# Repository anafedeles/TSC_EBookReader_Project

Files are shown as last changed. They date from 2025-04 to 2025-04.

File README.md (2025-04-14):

# TSC_EBookReader_Project

## 
Proiectul **EOpenBook** este o platformă portabilă cu afișaj E-Paper, construită în jurul microcontrollerului ESP32-C6, cu scopul de a oferi o interfață de citire eficientă energetic și complet conectată. Include funcționalități precum:

- Afișare E-Paper cu consum redus
- Stocare locală pe memorie NOR și card microSD
- Monitorizare baterie și încărcare
- Ceas în timp real (RTC)
- Senzor de mediu cu detecție VOC
- Protecții ESD și rutare optimizată

## Diagramă bloc cu toate componentele proiectului
Copie a fișierului Diagrama Bloc

## Listă de materiale (BOM)

| Componentă | Link pentru achizitionare | Link Datasheet |
|---|---|---|
| 112A-TAAR-R03 ATTEND | https://store.comet.srl.ro/Catalogue/Product/43497/ | https://www.snapeda.com/parts/112A-TAAR-R03/Attend/datasheet/ |
| BD5229G-TR | https://www.digikey.com/en/products/detail/rohm-semiconductor/BD5229G-TR/3663792 | https://fscdn.rohm.com/en/products/databook/datasheet/ic/power/voltage_detector/bd52xxg-e.pdf |
| ESP32 WROVER BME680 Sensor | https://store.comet.srl.ro/Catalogue/Product/50164/ | https://www.bosch-sensortec.com/media/boschsensortec/downloads/datasheets/bst-bme680-ds001.pdf |
| LED CHG_LED | https://ro.mouser.com/ProductDetail/Kingbright/KP-1608SURCK?qs=2JU0tDl2GZ3FuyEWfBV1%2Fg== | https://www.snapeda.com/parts/KP-1608SURCK/Kingbright/datasheet/ |
| Condensator C0402 | https://ro.mouser.com/c/passive-components/capacitors/ceramic-capacitors/?q=CC0402 | https://componentsearchengine.com/Datasheets/2/CC0402MRX5R5BB106.pdf |
| Condensator Tant  | https://ro.mouser.com/ProductDetail/KYOCERA-AVX/TAJW107M010RNJ?qs=Wtp%252Bf%2FAeVqIH8v1VxV%252B1Rg%3D%3D | https://ro.mouser.com/datasheet/2/40/TAJ-3165264.pdf |
|Q1 DMG2305UX-7 | https://www.digikey.com/en/products/detail/diodes-incorporated/DMG2305UX-7/4340666 | https://www.diodes.com/assets/Datasheets/DMG2305UX.pdf |
| RTC MODULE DS3231SN# | https://www.snapeda.com/parts/DS3231SN%23/Analog+Devices/view-part/?ref=eda | https://www.snapeda.com/parts/DS3231SN%23/Analog%20Devices/datasheet/ |
| ESP32 C6 WROOM-1-N8 | https://ro.mouser.com/ProductDetail/Espressif-Systems/ESP32-C6-WROOM-1-N8?qs=8Wlm6%252BaMh8ST02Gmwp74cw%3D%3D | https://www.snapeda.com/parts/ESP32-C6-WROOM-1-N8/Espressif%20Systems/datasheet/ |
| FH34SRJ-24S-0.5SH(99)  | https://ro.mouser.com/ProductDetail/Hirose-Connector/FH34SRJ-24S-0.5SH99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 | https://www.snapeda.com/parts/FH34SRJ-24S-0.5SH(99)/Hirose%20Connector/datasheet/ |
| MAX 17048G+T10 | https://www.snapeda.com/parts/MAX17048G+T10/Analog+Devices/view-part/?ref=eda  | https://www.snapeda.com/parts/MAX17048G+T10/Analog%20Devices/datasheet/ |
| MBR0530 Schottky Diode | https://www.snapeda.com/parts/MBR0530/Onsemi/view-part/?ref=snap | https://www.snapeda.com/parts/MBR0530/ON%20Semiconductor/datasheet/ |
| ESP32 WROVER MCP73831 Power Management | ]https://www.snapeda.com/parts/BME680/Bosch/view-part/?welcome=home | https://www.snapeda.com/parts/MCP73831T-2ACI/OT/Microchip/datasheet/ |
| PFMF.050.1 | https://ro.mouser.com/ProductDetail/EPCOS-TDK/B72520T0350K062?qs=dEfas%2FXlABIszF52uu7vrg%3D%3D | https://www.tdk-electronics.tdk.com/inf/75/db/CTVS_14/Surge_protection_series.pdf |
| PGB1010603MR | https://www.snapeda.com/parts/PGB1010603MR/Littelfuse/view-part/?ref=eda | https://www.snapeda.com/parts/PGB1010603MR/Littelfuse%20Inc./datasheet/ |
| QWIIC_RIGHT_ANGLE CONNECTOR | https://ro.mouser.com/ProductDetail/SparkFun/PRT-14417?qs=wd5RIQLrsJhgdz%2FpmZ%2F3GQ== | https://ro.mouser.com/datasheet/2/813/Qwiic_Connector_Datasheet-1223982.pdf |
| Rezistență R0402 | https://grabcad.com/library/resistor-0402-1)  | https://www.yageo.com/upload/media/product/products/datasheet/rchip/PYu-RC_Group_51_RoHS_L_12.pdf |
| SD0805S020S1R0 | https://ro.mouser.com/ProductDetail/KYOCERA-AVX/SD0805S020S1R0?qs=jCA%252BPfw4LHbpkAoSnwrdjw%3D%3D | https://ro.mouser.com/datasheet/2/40/schottky-3165252.pdf |
| Si1308EDL-T1-GE3 MOSFET | https://www.snapeda.com/parts/SI1308EDL-T1-GE3/Vishay+Siliconix/view-part/?welcome=home&ref=eda | https://www.snapeda.com/parts/SI1308EDL-T1-GE3/Vishay%20Siliconix/datasheet/ |
| USB4110-GF-A | https://ro.mouser.com/ProductDetail/GCT/USB4110-GF-A?qs=KUoIvG%2F9IlYiZvIXQjyJeA%3D%3D | https://ro.mouser.com/datasheet/2/837/GCT_USB4110_Product_Drawing___20k_cycles-3455479.pdf |
| USBLC6-2SC6Y | https://ro.mouser.com/ProductDetail/STMicroelectronics/USBLC6-2SC6Y?qs=gNDSiZmRJS%2FOgDexvXkdow%3D%3D | https://ro.mouser.com/datasheet/2/389/usblc6_2sc6y-1852505.pdf |
| W25Q512JVEIQ | ]https://www.snapeda.com/parts/W25Q512JVEIQ/Winbond+Electronics/view-part/?ref=eda) | https://www.winbond.com/resource-files/W25Q512JV%20SPI%20RevB%2006252019%20KMS.pdf) |
| XC6220A331MR-G | https://componentsearchengine.com/part-view/XC6220A331MR-G/Torex | https://product.torexsemi.com/system/files/series/xc6220.pdf |
| 744043680 BOBINA  | https://ro.mouser.com/ProductDetail/Wurth-Elektronik/744043680?qs=PGXP4M47uW6VkZq%252BkzjrHA%3D%3D | https://www.we-online.com/components/products/datasheet/744043680.pdf |

## Funcționalitatea Hardware 
ESP32-C6 este nucleul EOpenBook-ului, oferind conectivitate Wi-Fi 6 și Bluetooth 5.0 LE. Acesta include:

### Procesor RISC-V single-core de 160MHz
512KB de SRAM
8MB de memorie flash externă
Conectivitate wireless integrată
Multiple pini GPIO pentru interfațarea cu componente periferice

### Afișaj E-Paper

Afișajul e-paper oferă o interfață vizuală cu consum redus pentru EBook
Conectat prin interfața SPI la ESP32-C6
Utilizează driver-ul BD5229G-TR pentru a gestiona diversele tensiuni necesare afișajului
Alimentarea afișajului este controlată de MOSFET-uri pentru a asigura oprirea completă când nu este utilizat
Conectorul afișajului (FH34SRJ-24S-0.5SH) oferă o conexiune fiabilă la modulul flexibil de afișare

### Senzor de Mediu

Senzorul BME688 oferă măsurători pentru:

Temperatură (precizie ±0.5°C)
Umiditate (precizie ±3% RH)
Presiune (precizie ±0.12 hPa)
Calitatea aerului (detectare VOC)
Conectat prin interfața I²C (SCL/SDA)
Funcționează la 3.3V cu un consum tipic de curent de 3.7mA în timpul măsurătorilor

### Gestionarea Energiei

Conector USB-C (112A-TAAR-R03) pentru alimentare și comunicare de date
USBLC6-2SC6Y oferă protecție ESD pentru liniile USB
MCP73831 controller pentru încărcarea bateriei Li-Ion/Li-Polymer cu o singură celulă:

Curent de încărcare programabil până la 500mA
Terminare automată a încărcării
Indicare status prin LED

MAX17048G+T10 monitorizează starea bateriei:

Oferă o estimare precisă a stării de încărcare (SoC)
Comunică prin I²C
Consum redus de energie (23μA)

XC6220A331MR-G LDO oferă o ieșire stabilă de 3.3V:

Interval de tensiune de intrare: 2.0V până la 6.0V
Curent de ieșire până la 700mA
Tensiune de dropout scăzută (90mV tipic la 100mA)

### Ceas în Timp Real

DS3231SN RTC de înaltă precizie:

Oscilator cu cristal compensat în temperatură (TCXO)
Precizie ±2ppm (±1 minut pe an)
Baterie de backup folosind un supercondensator
Interfață I²C pentru comunicare
Funcții de alarmă cu capacitate de întrerupere

### Stocare Externă

W25Q512JVEIQ 512Mb (64MB) Flash NOR Serial:

Interfață SPI la până la 133MHz
100.000 de cicluri de programare/ștergere
Retenție date: 20 de ani
Folosit pentru stocarea datelor aplicației, configurare și actualizări firmware

Interfață card SD pentru stocare extensibilă:

Conectată prin interfață SPI
Suportă formate standard de card SD

### Protecție ESD

Diodele PGB1010603MR protejează liniile SPI sensibile
USBLC6-2SC6Y protejează liniile de date USB
Layout-ul atent al PCB-ului cu planuri de masă și rutare corespunzătoare îmbunătățește performanța EMI/EMC

### Analiza Consumului de Energie

Mod de repaus: <50μA (ESP32-C6 în deep sleep, RTC activ)
Mod inactiv: ~25mA (ESP32-C6 treaz, periferice în standby)
Mod activ: ~150mA (toate sistemele active, fără a include reîmprospătarea afișajului)
Reîmprospătare afișaj: ~20mA vârf în timpul reîmprospătării, 0mA când este static
Estimare durată de viață a bateriei:

Cu o baterie tipică LiPo de 2000mAh
~80 de ore de funcționare continuă în mod inactiv
~2-3 săptămâni cu modele tipice de utilizare (treziri periodice și actualizări ale afișajului)

## Alocarea Pinilor ESP32-C6

| Componentă | Pini ESP32-C6 (funcție) | Note / Utilizare |
|---|---|---|
| **E-Paper Display** | IO3 (EPD_BUSY), IO5 (EPD_DC), IO6 (SCK), IO7 (MOSI), IO10 (EPD_CS), IO23 (EPD_RST), IO20 (EPD_3V3_C) | Interfață SPI; include semnalizare BUSY și control reset/alimentare |
| **Magistrala I2C** | IO21 (SDA), IO22 (SCL), IO19 (I2C_PW) | Comun pentru BME688, MAX17048, DS3231; I2C_PW pentru control alimentare senzori  |
| **RTC DS3231SN** | IO0 (INT_RTC), IO1 (32KHz), IO18 (RTC_RST) | Întrerupere externă, semnal 32KHz opțional, reset hardware |
| **USB** | IO12 (USB_D-), IO13 (USB_D+) | Comunicație USB cu PC |
| **UART** | IO16 (TX), IO17 (RX) | Comunicație serială pentru programare/debug |
| **Card SD** | IO2 (MISO), IO4 (SS_SD), IO6 (SCK), IO7 (MOSI) | SPI partajat; CS dedicat pentru card SD |
| **Memorie Flash NOR** | IO11 (FLASH_CS), IO2 (MISO), IO6 (SCK), IO7 (MOSI) | Partajează SPI cu SD și EPD; CS dedicat |
| **Butoane** | EN (RESET), IO8 (IO/BOOT), IO15 (IO/CHANGE) | BOOT pentru mod programare; CHANGE pentru acțiuni personalizate |
| **Alimentare & GND** | Pin 2 (3V3), Pin 1 (GND) | Alimentare stabilă 3.3V; masă comună |

Bus SPI: Bus-ul SPI este partajat între mai multe dispozitive (afișaj, flash, card SD) pentru a minimiza utilizarea pinilor. Fiecare dispozitiv are un pin dedicat de selectare a chip-ului pentru a asigura o comunicare corectă.
Bus I2C: Un singur bus I2C conectează toate dispozitivele I2C (BME688, RTC, indicator baterie) pentru a minimiza utilizarea pinilor, oferind în același timp o comunicare fiabilă la viteze standard (100kHz-400kHz).
Pini GPIO: Pinii cu capacitate de întrerupere (IO13, IO19) au fost selectați pentru funcții care necesită funcționalitate de trezire.
UART: Pinii standard UART (IO16/IO17) sunt utilizați pentru programare și depanare pentru a asigura compatibilitatea cu instrumentele standard de dezvoltare.
Gestionarea Energiei: Pinii de control pentru domeniile de alimentare sunt configurați pentru a permite controlul individual al perifericelor pentru o gestionare optimă a energiei.

## Detalii Suplimentare de Proiectare

Pentru a preveni eventualele erori la nivelul plăcii PCB, am ajustat dimensiunile anumitor footprint-uri și am corectat pad-urile, astfel încât să respecte normele de funcționare corespunzătoare. De asemenea, am aplicat regulile din checklist-ul de proiectare, inclusiv poziționarea condensatorilor de decuplare cât mai aproape de pinii VCC ai circuitelor integrate.
### Asezarea TP-urilor: 
TP-urile au fost amplasate strategic în apropierea marginilor plăcii de circuit imprimat și în vecinătatea componentelor cheie. Această alegere facilitează accesul pentru operațiunile de depanare și testare.
### Diode (Montare pe Suprafață ):
Designul inițial al amprentei pentru diode prezenta orificii de contact (pad holes) cu un diametru insuficient, ceea ce ar fi putut genera dificultăți semnificative în procesul de lipire. Pentru a asigura o fabricație fără probleme și o conexiune electrică solidă, dimensiunea acestor orificii a fost revizuită.
### Rutare și Plan de Masă: 
Rutarea traseelor a fost realizată atât pe stratul superior, cât și pe stratul inferior al PCB-ului. Această strategie a necesitat utilizarea unui total de 105 vias pentru a interconecta diferitele straturi și a permite o rutare complexă a semnalelor. Deși un număr mare de vias poate influența costul și complexitatea fabricației, utilizarea ambelor straturi oferă o flexibilitate sporită în distribuția semnalelor și a alimentării. Planul de masă (GND) a fost implementat după finalizarea rutării, fiind aplicat pe ambele straturi ale plăcii (superior și inferior). 
În realizarea designului am urmărit respectarea riguroasă a regulilor impuse de ERC și DRC. Amplasarea componentelor a fost realizată pe baza documentației tehnice disponibile (dimensiuni și recomandări de plasare), dar și ținând cont de cerințele de rutare și de asigurarea unei funcționări optime a dispozitivului.

## Concluzie

Designul hardware al proiectului **EOpenBook** îmbină performanța, eficiența energetică și modularitatea. Fiecare componentă a fost atent aleasă și integrată cu respectarea standardelor de proiectare (ERC/DRC). PCB-ul rezultat este pregătit pentru fabricație și testare, având o structură robustă, consum redus și compatibilitate excelentă cu cerințele mecanice.

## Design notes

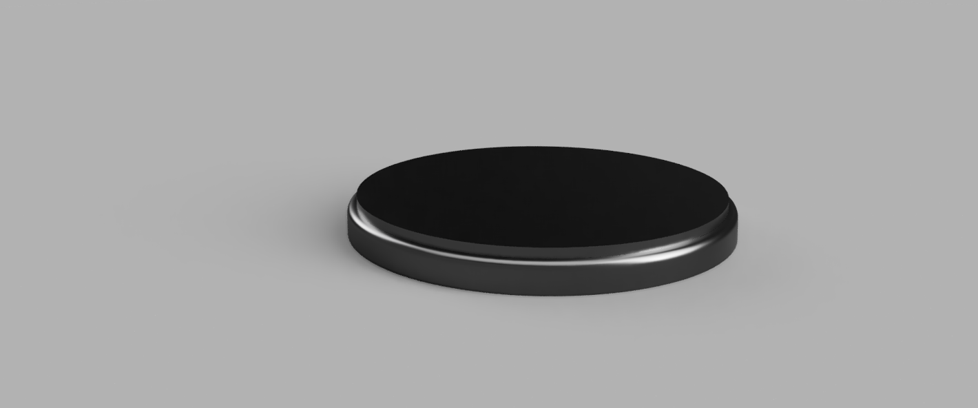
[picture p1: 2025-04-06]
Images/TP.jpg

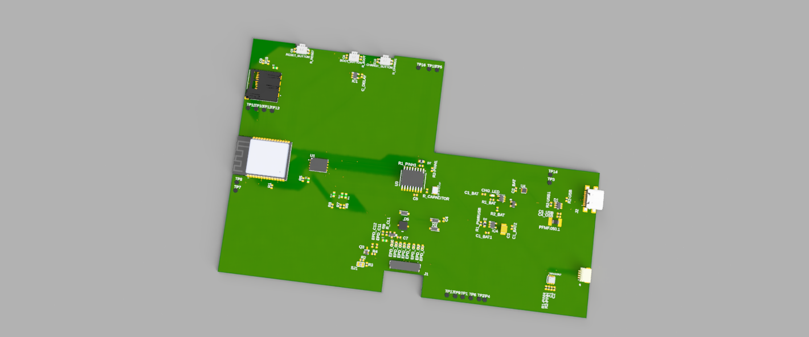
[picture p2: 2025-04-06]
Images/089be8cc-ee63-4535-a1ee-0e397a65c211.PNG

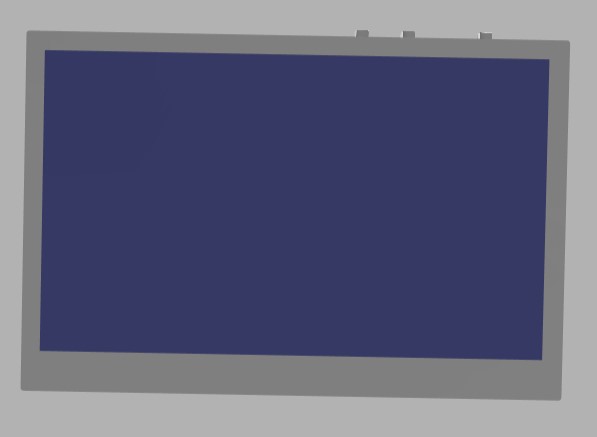
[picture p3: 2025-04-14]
Images/ebook.jpg

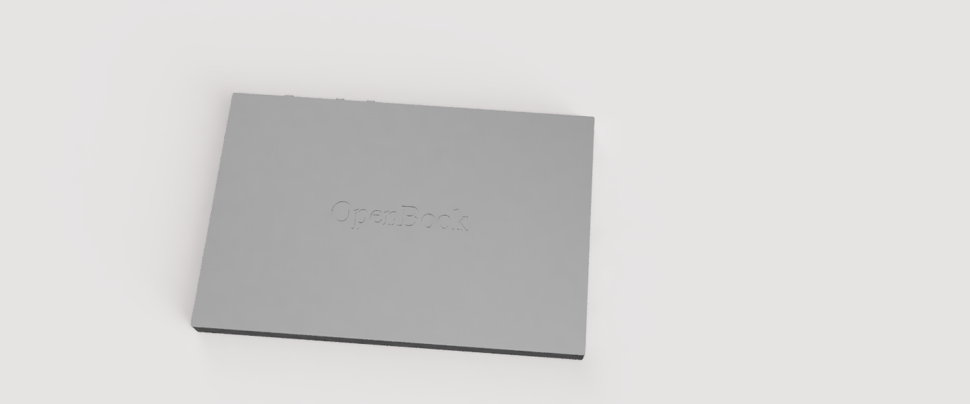
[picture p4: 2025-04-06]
Images/OpenBook_Enclosure_2025-Apr-06_06-05-44PM-000_CustomizedView23916758707.jpg

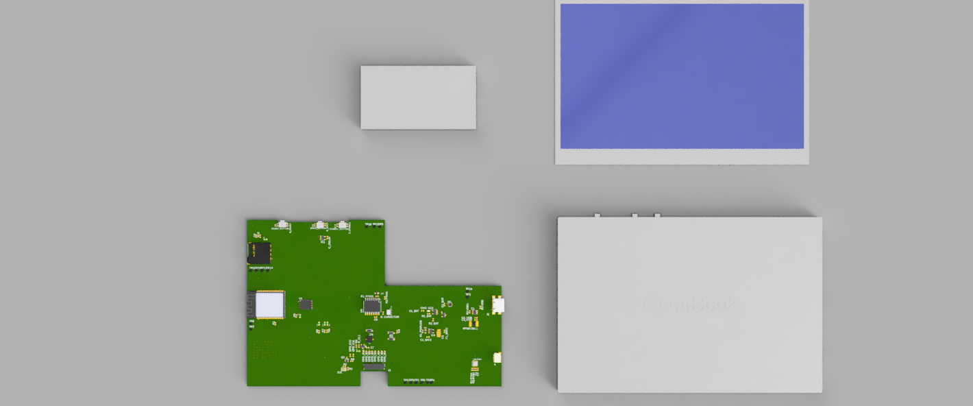
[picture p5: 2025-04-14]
Images/exploded_view_2_2025-Apr-14_11-00-59PM-000_CustomizedView40646485439.jpg

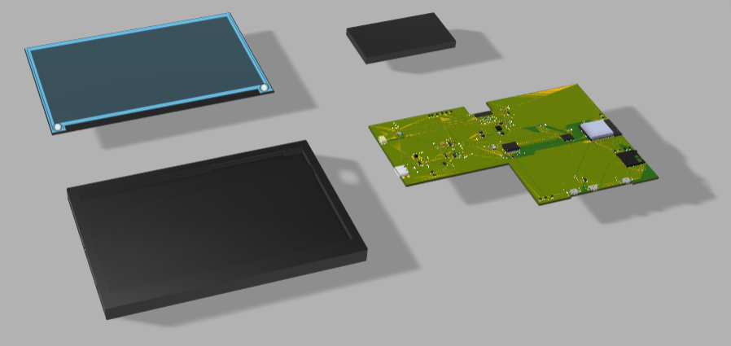
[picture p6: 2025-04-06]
Images/explode.png

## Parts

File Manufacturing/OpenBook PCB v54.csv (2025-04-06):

Qty | Value | Device | Package | Parts | Description | ARROW_PART_NUMBER | ARROW_PRICE-STOCK | AVAILABILITY | CHECK_PRICES | COPYRIGHT | DESCRIPTION | HEIGHT | MANUFACTURER_NAME | MANUFACTURER_PART_NUMBER | MF | MFR_NAME | MOUSER_PART_NUMBER | MOUSER_PRICE-STOCK | MOUSER_TESTING_PART_NUMBER | MOUSER_TESTING_PRICE-STOCK | MP | PACKAGE | POPULARITY | PRICE | PROD_ID | PURCHASE-URL | SNAPEDA_LINK | SPICEPREFIX | VALUE
1 |  | ADAFRUIT_LEDCHIP-LED0603 | ADAFRUIT_CHIP-LED0603 | CHG_LED | LED
1 |  | SJ | SJ | SJ1 | SMD solder JUMPER |  |  |  |  |  |  |  |  |  |  |  |  |  |  |  |  |  | 3
1 | 0.1uF/50V | ESP32_WROVER_EAGLE-LTSPICE_CC0402 | ESP32_WROVER_EAGLE-LTSPICE_C0402 | EPD_C5 | CAPACITOR, European symbol
1 | 0.47 | ESP32_WROVER_EAGLE-LTSPICE_RR0402 | ESP32_WROVER_EAGLE-LTSPICE_R0402 | R3 | RESISTOR, European symbol
1 | 100K | ESP32_WROVER_EAGLE-LTSPICE_RR0402 | ESP32_WROVER_EAGLE-LTSPICE_R0402 | R1_PWRUSB | RESISTOR, European symbol
8 | 100nF | ESP32_WROVER_EAGLE-LTSPICE_CC0402 | ESP32_WROVER_EAGLE-LTSPICE_C0402 | C1, C2, C4_USB, C6, C8, C9, C10, C_DELAY | CAPACITOR, European symbol
1 | 100uF TANT | RCL_CPOL-EUCT3528 | RCL_CT3528 | C3 | POLARIZED CAPACITOR, European symbol |  |  |  |  |  |  |  |  |  |  |  |  |  |  |  |  |  | 0 |  |  |  |  | C
16 | 10K | ESP32_WROVER_EAGLE-LTSPICE_RR0402 | ESP32_WROVER_EAGLE-LTSPICE_R0402 | R1, R1-PINH, R1_PINH1, R2-PINH, R2-PINH1, R4, R5, R6, R7, R8, R9, R10, R_BOOT, R_CHANGE, R_CL1, R_RESET | RESISTOR, European symbol
1 | 10uF | ESP32_WROVER_EAGLE-LTSPICE_CC0402 | ESP32_WROVER_EAGLE-LTSPICE_C0402 | C7 | CAPACITOR, European symbol
1 | 112A-TAAR-R03_ATTEND | 112A-TAAR-R03_ATTEND | 112ATAARR03ATTEND | J4 | Micro SD Card Socket, Push-Push Type, Top Mount, SMT, H=1.83mm, 10u |  |  |  |  |  | Micro SD Card Socket | Push-Push Type | Top Mount | SMT | H=1.83mm | 10u | 1.9mm | ATTEND | 112A-TAAR-R03 ATTEND
1 | 15 | ESP32_WROVER_EAGLE-LTSPICE_RR0402 | ESP32_WROVER_EAGLE-LTSPICE_R0402 | R_CAPACITOR | RESISTOR, European symbol
1 | 1uF | ESP32_WROVER_EAGLE-LTSPICE_CC0402 | ESP32_WROVER_EAGLE-LTSPICE_C0402 | C5 | CAPACITOR, European symbol
9 | 1uF/50V | ESP32_WROVER_EAGLE-LTSPICE_CC0402 | ESP32_WROVER_EAGLE-LTSPICE_C0402 | EPD_C1, EPD_C2, EPD_C6, EPD_C7, EPD_C8, EPD_C9, EPD_C10, EPD_C11, EPD_C12 | CAPACITOR, European symbol
1 | 2.2 | ESP32_WROVER_EAGLE-LTSPICE_RR0402 | ESP32_WROVER_EAGLE-LTSPICE_R0402 | R2 | RESISTOR, European symbol
1 | 200 | ESP32_WROVER_EAGLE-LTSPICE_RR0402 | ESP32_WROVER_EAGLE-LTSPICE_R0402 | R1_BAT | RESISTOR, European symbol
2 | 20V/4.2A/52mO/1.4W | ESP32_WROVER_SPARKFUN-DISCRETESEMI_MOSFET_PCH-DMG2305UX-7 | ESP32_WROVER_SPARKFUN-DISCRETESEMI_SOT23-3 | Q1, Q2 | P-channel MOSFETs
1 | 2K | ESP32_WROVER_EAGLE-LTSPICE_RR0402 | ESP32_WROVER_EAGLE-LTSPICE_R0402 | R2_BAT | RESISTOR, European symbol
5 | 4.7uF | ESP32_WROVER_EAGLE-LTSPICE_CC0402 | ESP32_WROVER_EAGLE-LTSPICE_C0402 | C1_BAT, C1_BAT1, C1_BAT2, C2_BAT, C5_USB | CAPACITOR, European symbol
1 | 4.7uF/25V | ESP32_WROVER_EAGLE-LTSPICE_CC0402 | ESP32_WROVER_EAGLE-LTSPICE_C0402 | C4 | CAPACITOR, European symbol
2 | 5k1 | ESP32_WROVER_EAGLE-LTSPICE_RR0402 | ESP32_WROVER_EAGLE-LTSPICE_R0402 | R2-USB, R2-USB1 | RESISTOR, European symbol
1 | 68uH | 744043680IND_4828-WE-TPC_WRE | IND_4828-WE-TPC_WRE | L1 |  |  |  |  |  | Copyright (C) 2024 Ultra Librarian. All rights reserved. |  |  |  | 744043680 |  | Wurth Electronics
1 | BD5229G-TR | BD5229G-TR | SOT95P280X125-5N | IC1 | Voltage Detector with Adjustable Delay Time: CMOS processes are utilized to develop high precision, low current consumption CMOS reset ICs that allow arbitrary setting of the delay time. The extensive lineup includes both Nch Open Drain and CMOS output types in a wide range of detection voltages (from 2.3V to 6.0V, in 0.1V steps), enabling selection of the ideal solution based on customer requirements. In addition, the entire series is of course both lead-free and RoHS-compliant. |  |  |  |  |  | Voltage Detector with Adjustable Delay Time: CMOS processes are utilized to develop high precision | low current consumption CMOS reset ICs that allow arbitrary setting of the delay time. The extensive lineup includes both Nch Open Drain and CMOS output types in a wide range of detection voltages (from 2.3V to 6.0V | in 0.1V steps) | enabling selection of the ideal solution based on customer requirements. In addition | the entire series is of course both lead-free and RoHS-compliant. | 1.25mm | ROHM Semiconductor | BD5229G-TR |  |  | 755-BD5229G-TR | https://www.mouser.co.uk/ProductDetail/ROHM-Semiconductor/BD5229G-TR?qs=4kLU8WoGk0vvnhrrYwdszw%3D%3D
1 | BME688 | ESP32_WROVER_BME680_BME680 | ESP32_WROVER_BME680_PSON80P300X300X100-8N | SENSOR2 | Integrated Environmental Unit |  |  | Unavailable |  |  | Integrated Environmental Unit |  |  |  | Bosch Sensortec |  |  |  |  |  | BME680 | LGA-8 Bosch Tools |  | None
3 | BUTTON_CUSYOMV1 | BUTTON_CUSYOMV1 | MYBUTTON | BOOT_BUTTON, CHANGE_BUTTON, RESET_BUTTON
1 | CPH3225A | CPH3225A | CAPCP3225X100N | C10_SUPERCAP | Cap 0.011F 3.3V 1210 Flat Check availability |  |  | Not in stock | https://www.snapeda.com/parts/CPH3225A/Seiko+Instruments/view-part/?ref=eda |  | 11 mF (EDLC) Supercapacitor 3.3 V 1210 (3225 Metric) - - |  |  |  | Seiko Instruments |  |  |  |  |  | CPH3225A | 1210 Seiko |  | None |  | https://www.snapeda.com/api/url_track_click_mouser/?unipart_id=562593&manufacturer=Seiko Instruments&part_name=CPH3225A&search_term=None | https://www.snapeda.com/parts/CPH3225A/Seiko+Instruments/view-part/?ref=snap
1 | DS3231SN# | DS3231SN# | SOIC127P1032X265-16N | U3 | Real Time Clock Serial 16-Pin SOIC W T/R Check availability |  |  | In Stock | https://www.snapeda.com/parts/DS3231SN%23/Analog+Devices/view-part/?ref=eda |  | Extremely Accurate I²C-Integrated RTC/TCXO/Crystal |  |  |  | Analog Devices |  |  |  |  |  | DS3231SN# | SOIC-16 Maxim |  | None |  | https://www.snapeda.com/api/url_track_click_mouser/?unipart_id=99048&manufacturer=Analog Devices&part_name=DS3231SN#&search_term=None | https://www.snapeda.com/parts/DS3231SN%23/Analog+Devices/view-part/?ref=snap
1 | ESP32-C6-WROOM-1-N8 | ESP32-C6-WROOM-1-N8 | XCVR_ESP32-C6-WROOM-1-N8 | U2 | Check availability |  |  | In Stock | https://www.snapeda.com/parts/ESP32-C6-WROOM-1-N8/Espressif+Systems/view-part/?ref=eda |  | Multiprotocol Modules ESP32-C6 module | Wi-Fi 6 in 2.4 GHz band | Bluetooth 5 | Zigbee 3.0 and Thread. ESP34-WROOM Compatible - ENGINEERING SAMPLE |  |  |  | Espressif Systems |  |  |  |  |  | ESP32-C6-WROOM-1-N8 | None |  | None
1 | ESP32C6_VARISTORCN1812 | ESP32C6_VARISTORCN1812 | ESP32C6_VARISTOR_CT/CN1812 | PFMF.050.1 | VARISTOR |  |  |  |  |  |  |  |  |  |  |  |  |  |  |  |  |  | 0
1 | ESP32_WROVER_AVX---SD0805S020S1R0_AVX_SD0805S020S1R0_0_0AVX_SD0805S020S1R0_0_0 | ESP32_WROVER_AVX---SD0805S020S1R0_AVX_SD0805S020S1R0_0_0AVX_SD0805S020S1R0_0_0 | ESP32_WROVER_AVX---SD0805S020S1R0_AVX_SD0805S020S1R0_0 | D2 | Schottky Barrier Rectifier Diode
1 | ESP32_WROVER_SPARKFUN-IC-POWER_MCP73831 | ESP32_WROVER_SPARKFUN-IC-POWER_MCP73831 | ESP32_WROVER_SPARKFUN-IC-POWER_SOT23-5 | MCP73831 | MCP73831T Li-Ion, Li-Pol Controller |  |  |  |  |  |  |  |  |  |  |  |  |  |  |  |  |  |  |  | IC-09995
1 | FH34SRJ-24S-0.5SH_99_ | FH34SRJ-24S-0.5SH_99_ | FH34SRJ24S05SH99 | J1 | (0.50mm) Surface Mount, Right Angle |  |  |  |  |  | 24 Position FFC | FPC Connector Contacts | (0.50mm) Surface Mount | Right Angle | 1.1mm | Hirose | FH34SRJ-24S-0.5SH(99) |  |  | 798-FH34SRJ24S05SH99 | https://www.mouser.co.uk/ProductDetail/Hirose-Connector/FH34SRJ-24S-0.5SH99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
1 | MAX17048G+T10 | MAX17048G+T10 | SON50P200X200X80-9N | U4 | Check availability |  |  | In Stock | https://www.snapeda.com/parts/MAX17048G+T10/Analog+Devices/view-part/?ref=eda |  | 3µA 1-Cell/2-Cell Fuel Gauge with ModelGauge |  |  |  | Analog Devices |  |  |  |  |  | MAX17048G+T10 | TDFN-8 Maxim |  | None |  | https://www.snapeda.com/api/url_track_click_mouser/?unipart_id=329239&manufacturer=Analog Devices&part_name=MAX17048G+T10&search_term=None | https://www.snapeda.com/parts/MAX17048G+T10/Analog+Devices/view-part/?ref=snap
3 |  |  | SOD3716X135N | D3, D4, D5 | ON SEMICONDUCTOR - MBR0530 - DIODE, SCHOTTKY, 0.5A, 30V, SOD-123
6 |  |  | DIOC1608X36N | D6, D8, D9, D10, D11, D12 | Check availability
1 | QWIIC_RIGHT_ANGLE | QWIIC_CONNECTORJS-1MM | JST04_1MM_RA | J3 | SparkFun I2C Standard Qwiic Connector |  |  |  |  |  |  |  |  |  |  |  |  |  |  |  |  |  |  |  | CONN-13694 |  |  |  | QWIIC_RIGHT_ANGLE
1 | SAMACSYS_PARTS_USB4110-GF-A | SAMACSYS_PARTS_USB4110-GF-A | SAMACSYS_PARTS_USB4110GFA | J2 | CONN USB 2.0 TYPE-C R/A SMT |  |  |  |  |  | CONN USB 2.0 TYPE-C R/A SMT | 3.26mm | GCT (GLOBAL CONNECTOR TECHNOLOGY) | USB4110-GF-A |  |  | 640-USB4110-GF-A | https://www.mouser.co.uk/ProductDetail/GCT/USB4110-GF-A?qs=KUoIvG%2F9IlYiZvIXQjyJeA%3D%3D
1 | SD0805S020S1R0 | ESP32_WROVER_AVX---SD0805S020S1R0_AVX_SD0805S020S1R0_0_0AVX_SD0805S020S1R0_0_0 | ESP32_WROVER_AVX---SD0805S020S1R0_AVX_SD0805S020S1R0_0 | D7 | Schottky Barrier Rectifier Diode
1 | SI1308EDL-T1-GE3 | SI1308EDL-T1-GE3 | SOT65P210X110-3N | Q3 | MOSFET N-Ch 30V 1.5A TrenchFET SC70 Vishay Si1308EDL-T1-GE3 N-channel MOSFET Transistor, 1.5 A, 30 V, 3-Pin SC-70 |  |  | In Stock | https://www.snapeda.com/parts/SI1308EDL-T1-GE3/Vishay+Siliconix/view-part/?ref=eda |  | Si1308EDL-T1-GE3 N-channel MOSFET Transistor | 1.5 A | 30 V | 3-Pin SC-70 | Siliconix / Vishay SI1308EDL-T1-GE3 |  |  |  | Vishay Siliconix |  |  |  |  |  | SI1308EDL-T1-GE3 | SOT-323 Vishay Semiconductor |  | None |  | https://www.snapeda.com/api/url_track_click_mouser/?unipart_id=274603&manufacturer=Vishay Siliconix&part_name=SI1308EDL-T1-GE3&search_term=None
16 | TPTP20R | TPTP20R | TP20R | TP1, TP2, TP3, TP4, TP5, TP6, TP8, TP9, TP10, TP11, TP12, TP13, TP14, TP15, TP16, TP17 | Test pad
1 | TPTP20R | TPTP20R | TP20R | TP7 | Test pad |  |  |  |  |  |  |  |  |  |  |  |  |  |  |  |  |  |  |  |  |  |  | X
1 | USBLC6-2SC6Y | USBLC6-2SC6Y | SOT95P280X145-6N | D1 | Low Cap. ESD Protection Auto SOT-23-6 STMicroelectronics USBLC6-2SC6Y, Dual Uni-Directional TVS Diode Array, 6-Pin SOT-23 |  |  | In Stock | https://www.snapeda.com/parts/USBLC6-2SC6Y/STMicroelectronics/view-part/?ref=eda |  | 17V Clamp 5A (8/20µs) Ipp Tvs Diode Surface Mount SOT-23-6 |  |  |  | STMicroelectronics |  |  |  |  |  | USBLC6-2SC6Y | SOT-23-6 STMicroelectronics |  | None |  |  | https://www.snapeda.com/parts/USBLC6-2SC6Y/STMicroelectronics/view-part/?ref=snap
1 | W25Q512JVEIQ | W25Q512JVEIQ | SON127P600X800X80-9N | U1 | Check availability |  |  | In Stock | https://www.snapeda.com/parts/W25Q512JVEIQ/Winbond+Electronics/view-part/?ref=eda |  | FLASH - NOR Memory IC 512Mb (64M x 8) SPI - Quad I/O 133 MHz 8-WSON (8x6) |  |  |  | Winbond Electronics |  |  |  |  |  | W25Q512JVEIQ | Package |  | None |  |  | https://www.snapeda.com/parts/W25Q512JVEIQ/Winbond+Electronics/view-part/?ref=snap
1 | XC6220A331MR-G | XC6220A331MR-G | SOT95P280X120-5N | IC4 | LDO Voltage Regulators |  |  |  |  |  | LDO Voltage Regulators | 1.2mm | Torex | XC6220A331MR-G |  |  | 865-XC6220A331MR-G | https://www.mouser.co.uk/ProductDetail/Torex-Semiconductor/XC6220A331MR-G?qs=AsjdqWjXhJ8ZSWznL1J0gg%3D%3D

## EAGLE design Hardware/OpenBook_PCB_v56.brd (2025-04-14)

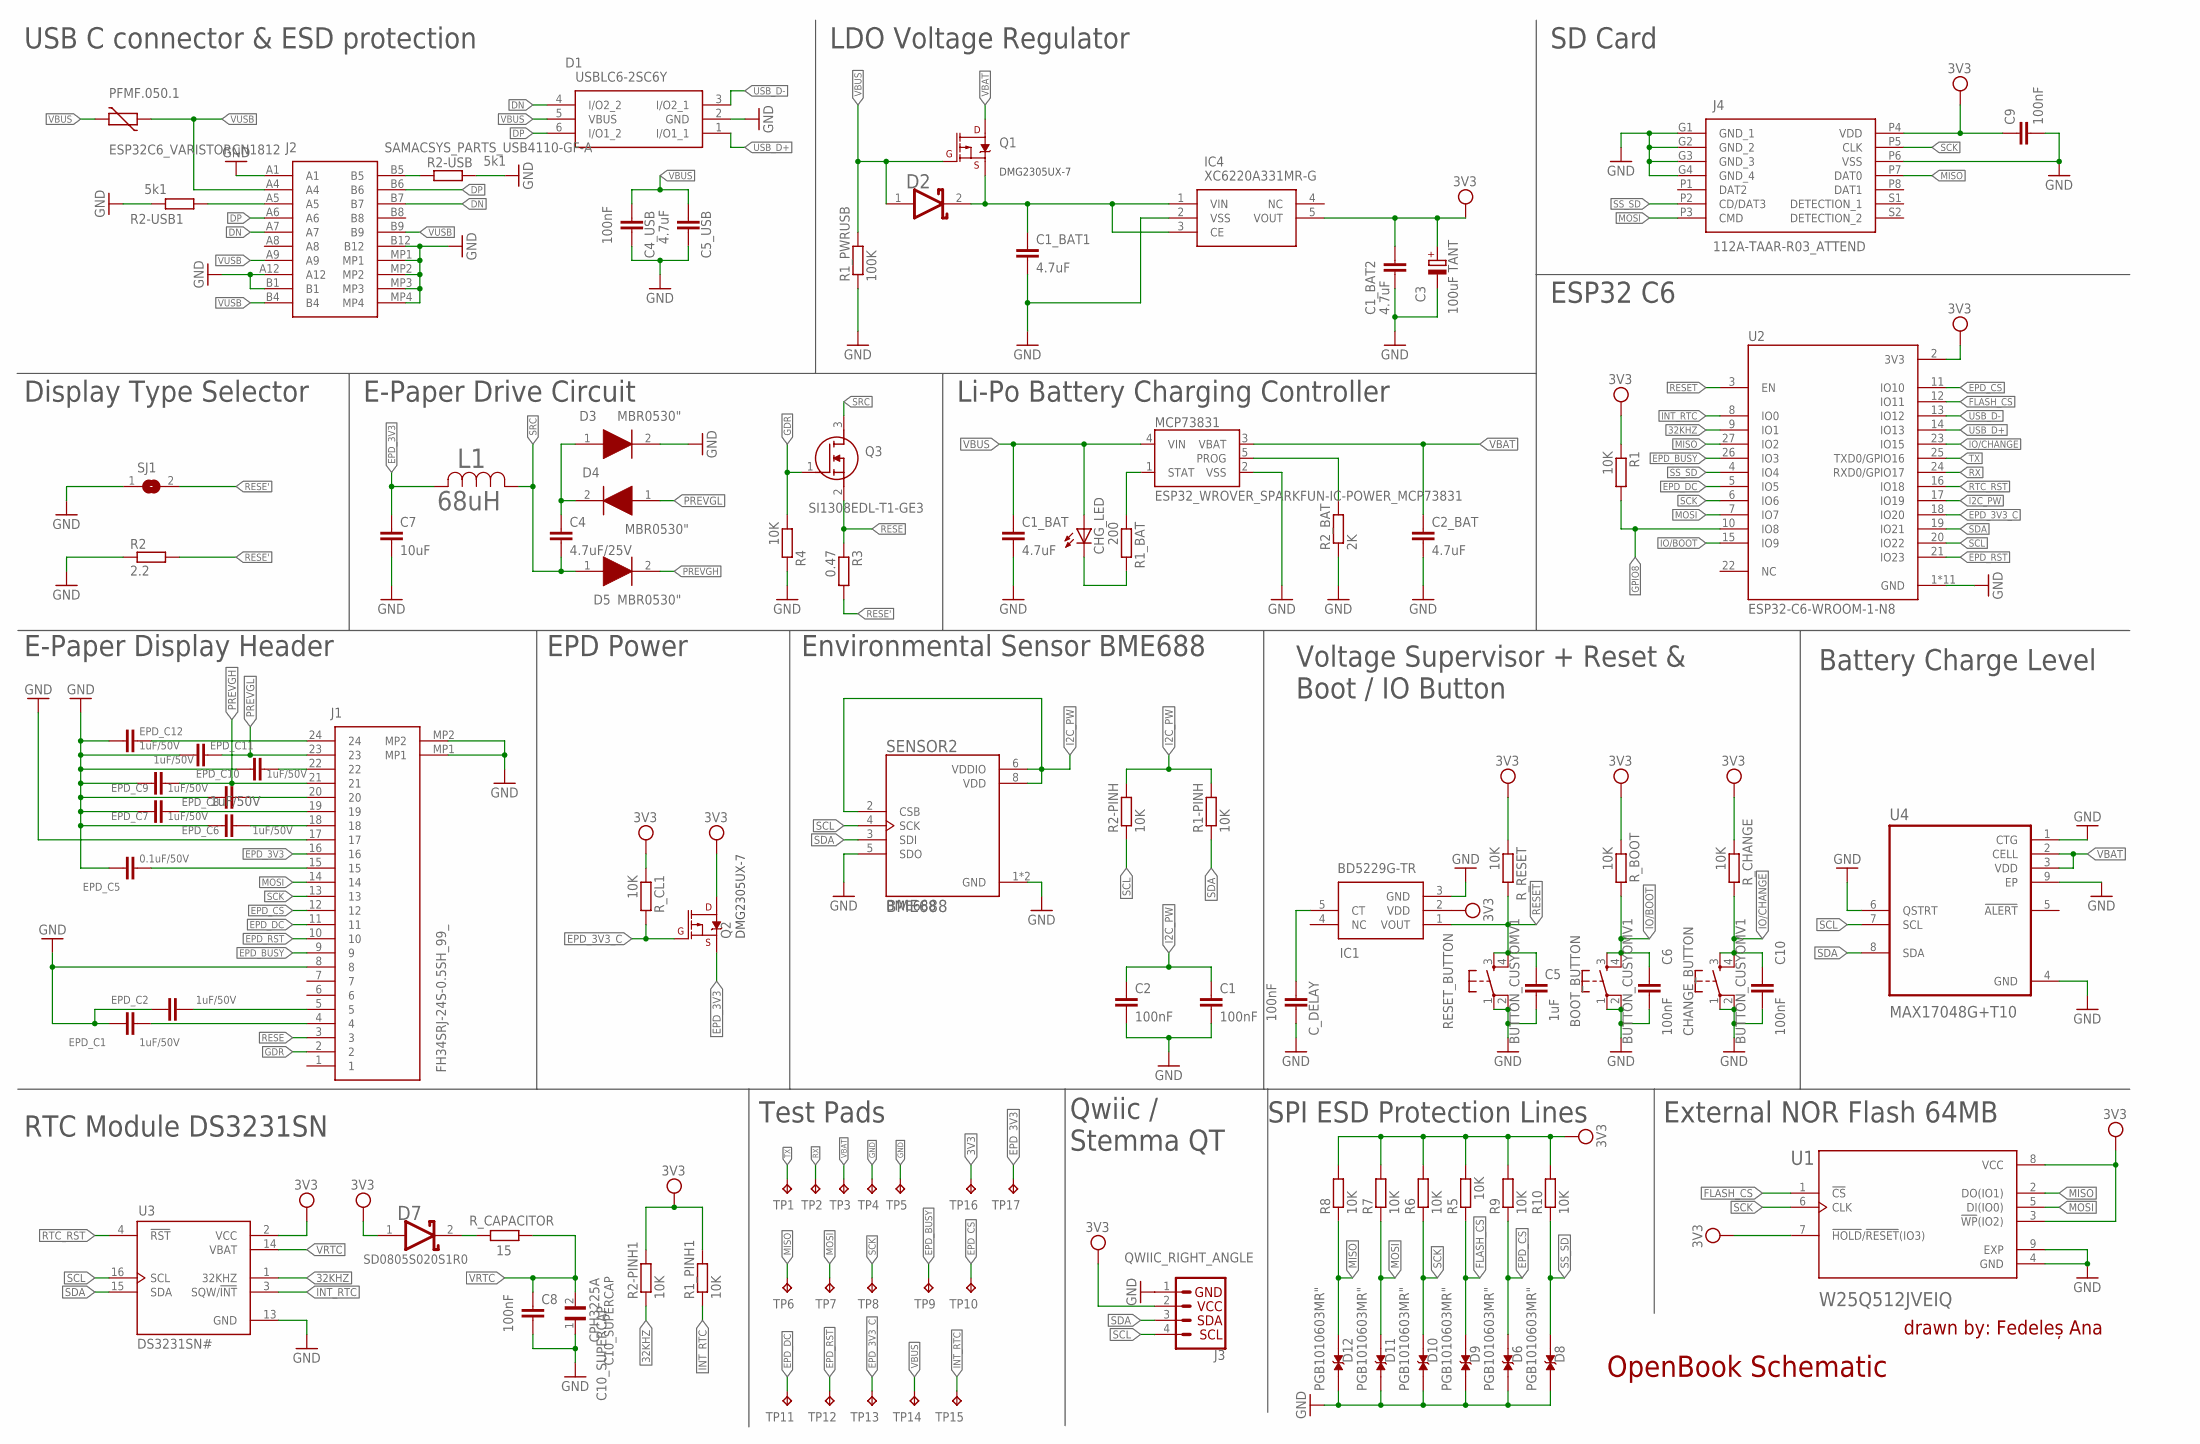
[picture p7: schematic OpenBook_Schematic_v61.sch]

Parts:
BOOT_BUTTON: BUTTON_CUSYOMV1; MYBUTTON
C1, C2, C4_USB, C6, C8, C9, C10: 100nF; ESP32_WROVER_EAGLE-LTSPICE_C0402
C1_BAT, C1_BAT1, C1_BAT2, C2_BAT, C5_USB: 4.7uF; ESP32_WROVER_EAGLE-LTSPICE_C0402
C3: 100uF TANT; RCL_CT3528
C4: 4.7uF/25V; ESP32_WROVER_EAGLE-LTSPICE_C0402
C5: 1uF; ESP32_WROVER_EAGLE-LTSPICE_C0402
C7: 10uF; ESP32_WROVER_EAGLE-LTSPICE_C0402
C10_SUPERCAP: CPH3225A; CAPCP3225X100N
CHANGE_BUTTON: BUTTON_CUSYOMV1; MYBUTTON
CHG_LED: ADAFRUIT_LEDCHIP-LED0603; ADAFRUIT_CHIP-LED0603
C_DELAY: 100nF; ESP32_WROVER_EAGLE-LTSPICE_C0402
D1: USBLC6-2SC6Y; SOT95P280X145-6N
D2: ESP32_WROVER_AVX---SD0805S020S1R0_AVX_SD0805S020S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; ESP32_WROVER_AVX---SD0805S020S1R0_AVX_SD0805S020S1R0_0
D3, D4, D5: MBR0530"; SOD3716X135N
D6, D8, D9, D10, D11, D12: PGB1010603MR"; DIOC1608X36N
D7: SD0805S020S1R0; ESP32_WROVER_AVX---SD0805S020S1R0_AVX_SD0805S020S1R0_0
EPD_C1, EPD_C2, EPD_C6, EPD_C7, EPD_C8, EPD_C9, EPD_C10, EPD_C11, EPD_C12: 1uF/50V; ESP32_WROVER_EAGLE-LTSPICE_C0402
EPD_C5: 0.1uF/50V; ESP32_WROVER_EAGLE-LTSPICE_C0402
IC1: BD5229G-TR; SOT95P280X125-5N
IC4: XC6220A331MR-G; SOT95P280X120-5N
J1: FH34SRJ-24S-0.5SH_99_; FH34SRJ24S05SH99
J2: SAMACSYS_PARTS_USB4110-GF-A; SAMACSYS_PARTS_USB4110GFA
J3: QWIIC_RIGHT_ANGLE; JST04_1MM_RA
J4: 112A-TAAR-R03_ATTEND; 112ATAARR03ATTEND
L1: 68uH; IND_4828-WE-TPC_WRE
MCP73831: ESP32_WROVER_SPARKFUN-IC-POWER_MCP73831; ESP32_WROVER_SPARKFUN-IC-POWER_SOT23-5
PFMF.050.1: ESP32C6_VARISTORCN1812; ESP32C6_VARISTOR_CT/CN1812
Q1, Q2: 20V/4.2A/52mΩ/1.4W; ESP32_WROVER_SPARKFUN-DISCRETESEMI_SOT23-3
Q3: SI1308EDL-T1-GE3; SOT65P210X110-3N
R1, R1-PINH, R1_PINH1, R2-PINH, R2-PINH1, R4, R5, R6, R7, R8, R9, R10: 10K; ESP32_WROVER_EAGLE-LTSPICE_R0402
R1_BAT: 200; ESP32_WROVER_EAGLE-LTSPICE_R0402
R1_PWRUSB: 100K; ESP32_WROVER_EAGLE-LTSPICE_R0402
R2: 2.2; ESP32_WROVER_EAGLE-LTSPICE_R0402
R2-USB, R2-USB1: 5k1; ESP32_WROVER_EAGLE-LTSPICE_R0402
R2_BAT: 2K; ESP32_WROVER_EAGLE-LTSPICE_R0402
R3: 0.47; ESP32_WROVER_EAGLE-LTSPICE_R0402
RESET_BUTTON: BUTTON_CUSYOMV1; MYBUTTON
R_BOOT: 10K; ESP32_WROVER_EAGLE-LTSPICE_R0402
R_CAPACITOR: 15; ESP32_WROVER_EAGLE-LTSPICE_R0402
R_CHANGE: 10K; ESP32_WROVER_EAGLE-LTSPICE_R0402
R_CL1: 10K; ESP32_WROVER_EAGLE-LTSPICE_R0402
R_RESET: 10K; ESP32_WROVER_EAGLE-LTSPICE_R0402
SENSOR2: BME688; ESP32_WROVER_BME680_PSON80P300X300X100-8N
SJ1: SJ
TP1, TP2, TP3, TP4, TP5, TP6, TP7, TP8, TP9, TP10, TP11, TP12, TP13, TP14, TP15, TP16, TP17: TPTP20R; TP20R
U1: W25Q512JVEIQ; SON127P600X800X80-9N
U2: ESP32-C6-WROOM-1-N8; XCVR_ESP32-C6-WROOM-1-N8
U3: DS3231SN#; SOIC127P1032X265-16N
U4: MAX17048G+T10; SON50P200X200X80-9N

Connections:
3V3: C1_BAT2.1, C3.+, C9.1, D7.1 (ANODE), IC1.2 (VDD), IC4.5 (VOUT), J3.2, J4.P4 (VDD), Q2.1 (D), R1.1, R1_PINH1.2, R2-PINH1.2, R5.2, R6.2, R7.2, R8.2, R9.2, R10.2, R_BOOT.1, R_CHANGE.1, R_CL1.1, R_RESET.1, TP16.TP, U1.3 (!WP!(IO2)), U1.7 (!HOLD!/!RESET!(IO3)), U1.8 (VCC), U2.2 (3V3), U3.2 (VCC)
32KHZ: R2-PINH1.1, U2.9 (IO1), U3.1 (32KHZ)
DN: D1.4 (I/O2_2), J2.A7, J2.B7
DP: D1.6 (I/O1_2), J2.A6, J2.B6
EPD_3V3: C7.1, J1.16, L1.2, Q2.3 (S), TP17.TP
EPD_3V3_C: Q2.2 (G), R_CL1.2, TP13.TP, U2.18 (IO20)
EPD_BUSY: J1.9, TP9.TP, U2.26 (IO3)
EPD_CS: D6.2, J1.12, R9.1, TP10.TP, U2.11 (IO10)
EPD_DC: J1.11, TP11.TP, U2.5 (IO5)
EPD_RST: J1.10, TP12.TP, U2.21 (IO23)
FLASH_CS: D9.2, R5.1, U1.1 (!CS), U2.12 (IO11)
GDR: J1.2, Q3.1 (G), R4.1
GND: BOOT_BUTTON.1, BOOT_BUTTON.2, C1.2, C1_BAT.2, C1_BAT1.2, C1_BAT2.2, C2.2, C2_BAT.2, C3.-, C4_USB.2, C5.2, C5_USB.2, C6.2, C7.2, C8.2, C9.2, C10.2, C10_SUPERCAP.1, CHANGE_BUTTON.1, CHANGE_BUTTON.2, C_DELAY.2, D1.2 (GND), D3.2 (K), D6.1, D8.1, D9.1, D10.1, D11.1, D12.1, EPD_C1.2, EPD_C2.2, EPD_C5.2, EPD_C6.2, EPD_C7.2, EPD_C8.2, EPD_C9.2, EPD_C10.2, EPD_C11.2, EPD_C12.2, IC1.3 (GND), IC4.2 (VSS), J1.8, J1.17, J1.MP1, J1.MP2, J2.A1, J2.A12, J2.B1, J2.B12, J2.MP1, J2.MP2, J2.MP3, J2.MP4, J3.1, J4.G1 (GND_1), J4.G2 (GND_2), J4.G3 (GND_3), J4.G4 (GND_4), J4.P6 (VSS), MCP73831.2 (VSS), R1_PWRUSB.1, R2.1, R2-USB.2, R2-USB1.1, R2_BAT.1, R4.2, RESET_BUTTON.1, RESET_BUTTON.2, SENSOR2.1 (GND), SENSOR2.5 (SDO), SENSOR2.7 (GND), SJ1.1, TP4.TP, TP5.TP, U1.4 (GND), U1.9 (EXP), U2.1 (GND), U2.28 (GND), U2.29_1 (GND), U2.29_2 (GND), U2.29_3 (GND), U2.29_4 (GND), U2.29_5 (GND), U2.29_6 (GND), U2.29_7 (GND), U2.29_8 (GND), U2.29_9 (GND), U3.13 (GND), U4.1 (CTG), U4.4 (GND), U4.6 (QSTRT), U4.9 (EP)
GPIO8: R1.2, U2.10 (IO8)
I2C_PW: C1.1, C2.1, R1-PINH.2, R2-PINH.2, SENSOR2.2 (CSB), SENSOR2.6 (VDDIO), SENSOR2.8 (VDD), U2.17 (IO19)
INT_RTC: R1_PINH1.1, TP15.TP, U2.8 (IO0), U3.3 (SQW/!INT)
IO/BOOT: BOOT_BUTTON.3, BOOT_BUTTON.4, C6.1, R_BOOT.2, U2.15 (IO9)
IO/CHANGE: C10.1, CHANGE_BUTTON.3, CHANGE_BUTTON.4, R_CHANGE.2, U2.23 (IO15)
MISO: D12.2, J4.P7 (DAT0), R8.1, TP6.TP, U1.2 (DO(IO1)), U2.27 (IO2)
MOSI: D11.2, J1.14, J4.P3 (CMD), R7.1, TP7.TP, U1.5 (DI(IO0)), U2.7 (IO7)
unnamed: J2.A5, R2-USB1.2
unnamed: J2.B5, R2-USB.1
unnamed: MCP73831.1 (STAT), R1_BAT.1
unnamed: C1_BAT1.1, D2.2 (CATHODE), IC4.1 (VIN), IC4.3 (CE), Q1.3 (S)
unnamed: CHG_LED.C, R1_BAT.2
unnamed: EPD_C6.1, J1.18
unnamed: C_DELAY.1, IC1.5 (CT)
unnamed: C4.1, D3.1 (A), D4.2 (K)
unnamed: MCP73831.5 (PROG), R2_BAT.2
unnamed: EPD_C1.1, J1.4
unnamed: EPD_C2.1, J1.5
unnamed: EPD_C5.1, J1.15
unnamed: EPD_C8.1, J1.20
unnamed: EPD_C7.1, J1.19
unnamed: EPD_C10.1, J1.22
unnamed: EPD_C12.1, J1.24
unnamed: D7.2 (CATHODE), R_CAPACITOR.2
PREVGH: D5.2 (K), EPD_C9.1, J1.21
PREVGL: D4.1 (A), EPD_C11.1, J1.23
RESE: J1.3, Q3.2 (S), R3.1
RESE': R2.2, R3.2, SJ1.2
RESET: C5.1, IC1.1 (VOUT), RESET_BUTTON.3, RESET_BUTTON.4, R_RESET.2, U2.3 (EN)
RTC_RST: U2.16 (IO18), U3.4 (!RST)
RX: TP2.TP, U2.24 (RXD0/GPIO17)
SCK: D10.2, J1.13, J4.P5 (CLK), R6.1, TP8.TP, U1.6 (CLK), U2.6 (IO6)
SCL: J3.4, R2-PINH.1, SENSOR2.4 (SCK), U2.20 (IO22), U3.16 (SCL), U4.7 (SCL)
SDA: J3.3, R1-PINH.1, SENSOR2.3 (SDI), U2.19 (IO21), U3.15 (SDA), U4.8 (SDA)
SRC: C4.2, D5.1 (A), L1.1, Q3.3 (D)
SS_SD: D8.2, J4.P2 (CD/DAT3), R10.1, U2.4 (IO4)
TX: TP1.TP, U2.25 (TXD0/GPIO16)
USB_D+: D1.1 (I/O1_1), U2.14 (IO13)
USB_D-: D1.3 (I/O2_1), U2.13 (IO12)
VBAT: C2_BAT.1, MCP73831.3 (VBAT), Q1.1 (D), TP3.TP, U4.2 (CELL), U4.3 (VDD)
VBUS: C1_BAT.1, C4_USB.1, C5_USB.1, CHG_LED.A, D1.5 (VBUS), D2.1 (ANODE), MCP73831.4 (VIN), PFMF.050.1.2, Q1.2 (G), R1_PWRUSB.2, TP14.TP
VRTC: C8.1, C10_SUPERCAP.2, R_CAPACITOR.1, U3.14 (VBAT)
VUSB: J2.A4, J2.A9, J2.B4, J2.B9, PFMF.050.1.1

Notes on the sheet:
BME688
USB C connector & ESD protection
DMG2305UX-7
LDO Voltage Regulator
SD Card
Display Type Selector
E-Paper Drive Circuit
Li-Po Battery Charging Controller
ESP32 C6
E-Paper Display Header
EPD Power
Environmental Sensor BME688
Voltage Supervisor + Reset & Boot / IO Button
Battery Charge Level
SD0805S020S1R0
RTC Module DS3231SN
Test Pads
Qwiic / Stemma QT
SPI ESD Protection Lines
External NOR Flash 64MB
OpenBook Schematic
drawn by: Fedeleș Ana
C10_SUPERCAP

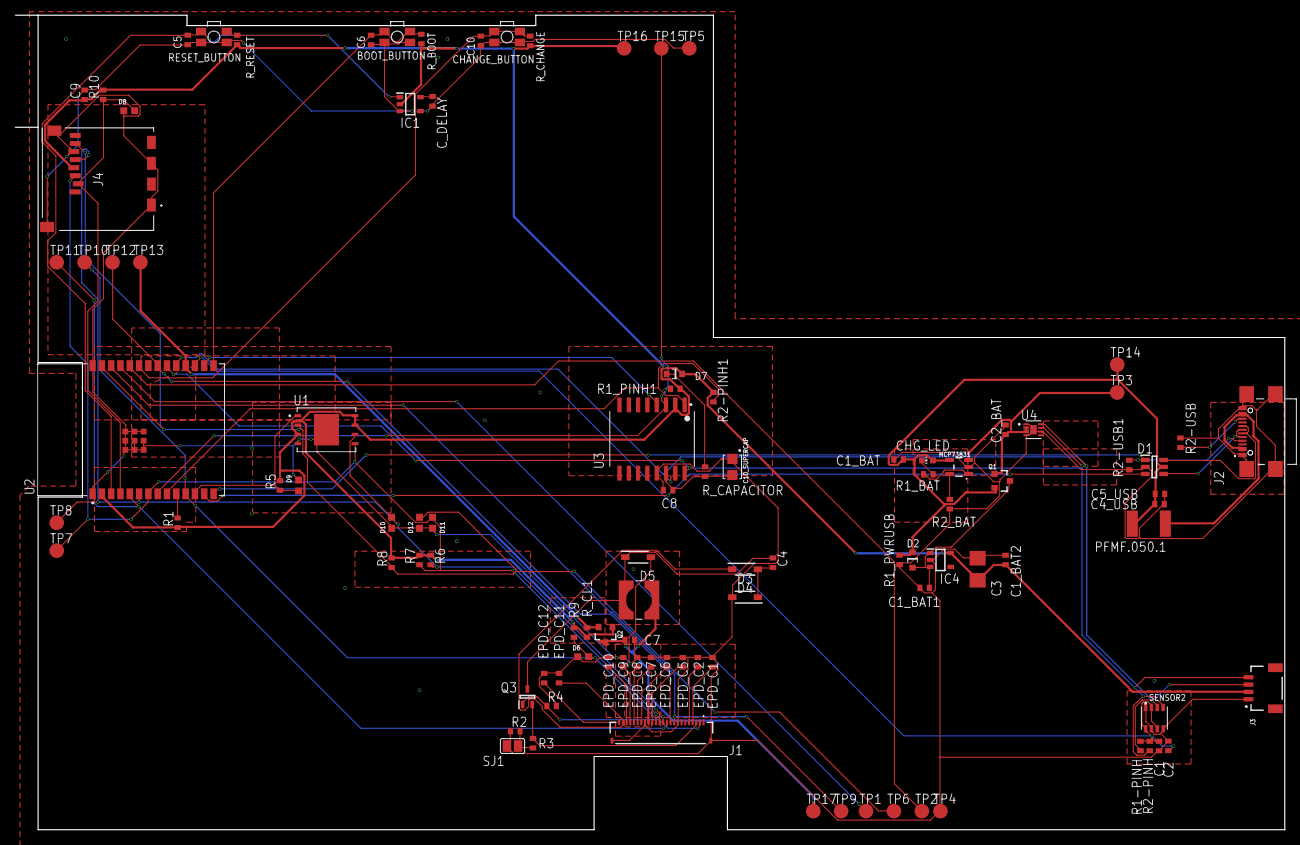
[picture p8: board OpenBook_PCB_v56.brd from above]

Board: 2 copper layers, 173.3 x 111.2 mm, 103 parts (0 on the bottom side), 56 nets.

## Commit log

2025-04-06 Hardware files uploaded
    [OpenBook_PCB_v54.brd, OpenBook_Schematic_v61.sch]
2025-04-06 Manufacturing files commited
    [OpenBook PCB v54.csv, PnP_OpenBook PCB v54_front.csv]
2025-04-06 Update PicknPlace_OpenBook PCB v54_front .csv
    [PicknPlace_OpenBook PCB v54_front .csv]
2025-04-06 Update PnP_OpenBook PCB v54_front.csv
    [PnP_OpenBook PCB v54_front.csv]
2025-04-14 Better Organization Mechnical Folder done
    [OpenBook_PCB.brd]
2025-04-14 Improved PCB- commit done
    [OpenBook_PCB_v56.brd]

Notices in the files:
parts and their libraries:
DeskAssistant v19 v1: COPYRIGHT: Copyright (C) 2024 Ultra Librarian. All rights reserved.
